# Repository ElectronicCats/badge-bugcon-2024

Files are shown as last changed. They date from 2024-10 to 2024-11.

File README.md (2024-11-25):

# Badge BugCON  2024

Badge Oficial BugCON 2024

## Getting started

1. Connect Badge via USB to your computer.
2. Open the serial port indicated for the badge on your computer through a program such as Arduino IDE, Putty or Screen at 115200 bauds.
3. The badge text should appear in the terminal.

## Tecnologia

### Community
- ESP32C6
- Baterias 2 x AA
- USB
- OLED 128×32 0.91 I2C SSD1306
- LEDS

### VIP
- ESP32C6
- Baterias 2 x AA
- USB
- GC9A01 Display TFT LCD Circular 1.28"
- LEDS

## How to build the firmware Community

Check the [Developer guide](./firmware/README.md) to learn how to build the firmware from scratch.

## How to build the firmware VIP

Check the [Developer guide CircuitPython](https://learn.adafruit.com/welcome-to-circuitpython/overview) to learn how to build the firmware from scratch.

Recommended development IDE [Thonny](https://thonny.org/)

## Gratitude
Do you want to say thank you? Tag these companies on social networks and show them your badge, thanks to them it is possible

- [BugCON Team](https://www.bugcon.org/)
- [ElectronicCats](https://electroniccats.com/)

## License

Electronic Cats invests time and resources providing this open source design, please support Electronic Cats and open-source hardware by purchasing products from Electronic Cats!

Designed by Electronic Cats.

Hardware released under an CERN Open Hardware Licence v1.2. See the LICENSE_HARDWARE file for more information.

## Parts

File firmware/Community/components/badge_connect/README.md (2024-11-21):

# Badge Connect library (Binary version)

This library is designed to provide a simple API in order to communicate electronic badges over a WiFi mesh network. It works using the [ESPNOW protocol](https://docs.espressif.com/projects/esp-idf/en/stable/esp32/api-reference/network/esp_now.html) developed by Espressif Systems.

## Features

- Send and receive messages between badges (messages can be of any data type)
- Set the badge's type (e.g. "BSides", "DragonJAR", "Ekoparty", and "BugCON")
- Get the badge's type

## Requirements

- At least two ESP32 development boards
- ESP-IDF installed in your computer
- `make` installed in your computer (optional)

## Installation

Add badge_connect_bin as a git submodule in your project.

```bash
git submodule add https://github.com/ElectronicCats/badge_connect_bin.git firmware/components/badge_connect
```

## Usage

1. Include the library in your source code.

```c
#include "badge_connect.h"
```

2. Initialize the library in your code.

```c
badge_connect_init();
```

3. Implement the callback function that will be called when a message is received.

```c
void receive_data_cb(badge_connect_recv_msg_t* msg) {
    // Do something with the received message
}
```

4. Register the callback function.

```c
badge_connect_register_recv_cb(receive_data_cb);
```

5. Set the badge's type, choose one of the following:

```c
badge_connect_set_bsides_badge();
badge_connect_set_dragonjar_badge();
badge_connect_set_ekoparty_badge();
badge_connect_set_bugcon_badge();
```

6. Send a message to another badge.

```c
char* data = "Hello, world!";
badge_connect_send(data, strlen(data));
```

7. Compile and flash!

## Examples

There is a folder called `examples` in this repository, you can use the `Makefile` in each example to compile and flash the firmware.

1. Get `idf.py` to your terminal session, if you followed the Espressif IDF installation guide, use `get_idf`.

```bash
get_idf
```

2. Go to the example folder you want to compile. For example, the `send_int` one.

```bash
cd examples/send_int
```

3. Set the board type you are using, skip if you are using an `ESP32`. For example, `ESP32-C6`.

```bash
idf.py set-target esp32c6
```

4. Set the serial port where the board is connected. For example, `/dev/ttyUSB0`.

```bash
export PORT=/dev/ttyUSB0
```

5. Compile, flash, and monitor the output.

```bash
make all
```

## License

Electronic Cats invests time and resources in providing this open-source design, please support Electronic Cats and open-source hardware by purchasing products from Electronic Cats!

Designed by Electronic Cats.

This library is released under a GNU AGPL v3.0 license. See the [LICENSE](LICENSE) file for more information.

Electronic Cats is a registered trademark, please do not use if you sell these PCBs.

June 2024

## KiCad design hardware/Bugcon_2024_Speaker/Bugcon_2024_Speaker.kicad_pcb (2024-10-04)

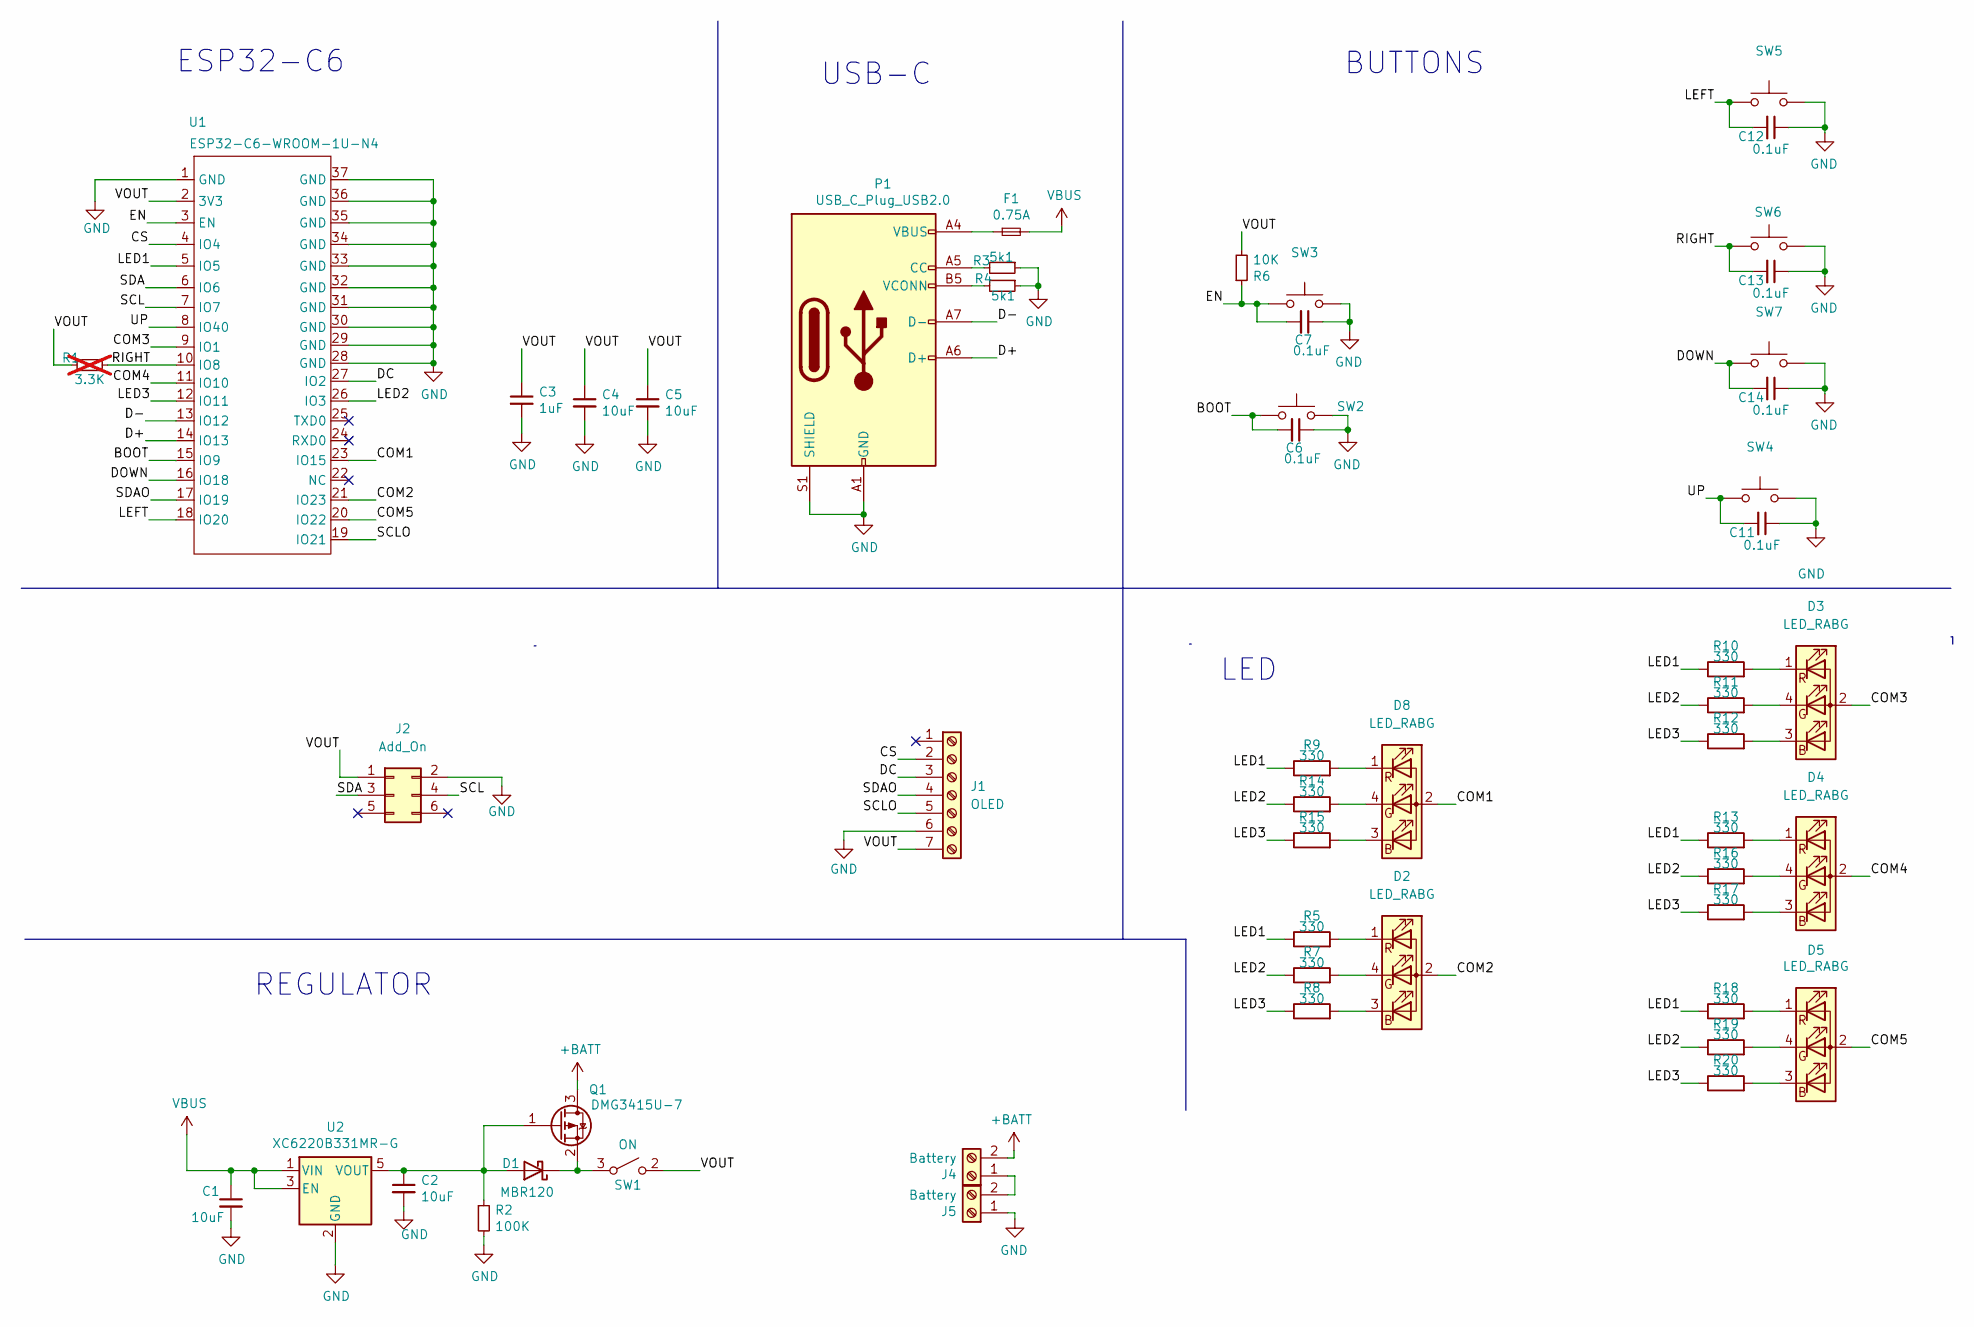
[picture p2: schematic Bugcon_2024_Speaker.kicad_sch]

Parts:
C1, C2, C4, C5: 10uF; C_0603_1608Metric; LCSC# C85713
C3: 1uF; C_0603_1608Metric; LCSC# C15849
C6, C7, C11, C12, C13, C14: 0.1uF; C_0603_1608Metric; LCSC# C478888
D1: MBR120; D_SOD-123F; LCSC# C130880
D2, D3, D4, D5, D8: LED_RABG; AAA3528SURKCGKC09
F1: 0.75A; Fuse_0805_2012Metric; LCSC# C1972808
J1: OLED; PinHeader_1x07_P2.54mm_Vertical
J2: Add_On; PinSocket_2x03_P2.54mm_Vertical; LCSC# C5116527
J4, J5: Battery; BATT_8BH-AA-A1AJ020_MYG; LCSC# C5290181
P1: USB_C_Plug_USB2.0; C393939; LCSC# C393939
Q1: DMG3415U-7; SOT-23; LCSC# C96616
R1: 3.3K; R_0603_1608Metric; LCSC# C403480; not fitted
R2: 100K; R_0603_1608Metric; LCSC# C25803
R3, R4: 5k1; R_0603_1608Metric; LCSC# C113390
R5, R7, R8, R9, R10, R11, R12, R13, R14, R15, R16, R17, R18, R19, R20: 330; R_0603_1608Metric; LCSC# C25231
R6: 10K; R_0603_1608Metric; LCSC# C217281
SW1: ON; MSK12C02; LCSC# C431540
SW2, SW3, SW4, SW5, SW6, SW7: SW_SPST_TL3342; LCSC# C318889
U1: ESP32-C6-WROOM-1U-N4; XCVR_ESP32-C6-WROOM-1-N8
U2: XC6220B331MR-G; SOT-23-5; LCSC# C86534

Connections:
+BATT: J4.2, Q1.3 (D)
/BOOT: C6.2, SW2.2, U1.15 (IO9)
/COM1: D8.2 (A), U1.23 (IO15)
/COM2: D2.2 (A), U1.21 (IO23)
/COM3: D3.2 (A), U1.9 (IO1)
/COM4: D4.2 (A), U1.11 (IO10)
/COM5: D5.2 (A), U1.20 (IO22)
/CS: J1.2, U1.4 (IO4)
/D+: P1.A6 (D+), U1.14 (IO13)
/D-: P1.A7 (D-), U1.13 (IO12)
/DC: J1.3, U1.27 (IO2)
/DOWN: C14.2, SW7.2, U1.16 (IO18)
/EN: C7.2, R6.1, SW3.2, U1.3 (EN)
/LED1: R5.1, R9.1, R10.1, R13.1, R18.1, U1.5 (IO5)
/LED2: R7.1, R11.1, R14.1, R16.1, R19.1, U1.26 (IO3)
/LED3: R8.1, R12.1, R15.1, R17.1, R20.1, U1.12 (IO11)
/LEFT: C12.2, SW5.2, U1.18 (IO20)
/RIGHT: C13.2, R1.1, SW6.2, U1.10 (IO8)
/SCL: J2.4, U1.7 (IO7)
/SCLO: J1.5, U1.19 (IO21)
/SDA: J2.3, U1.6 (IO6)
/SDAO: J1.4, U1.17 (IO19)
/UP: C11.2, SW4.2, U1.8 (IO40)
/VOUT: C3.1, C4.1, C5.1, J1.7, J2.1, R1.2, R6.2, SW1.2 (B), U1.2 (3V3)
GND: C1.2, C2.2, C3.2, C4.2, C5.2, C6.1, C7.1, C11.1, C12.1, C13.1, C14.1, J1.6, J2.2, J5.1, P1.A1 (GND), P1.A12 (GND), P1.B1 (GND), P1.B12 (GND), P1.S1 (SHIELD), R2.2, R3.1, R4.1, SW2.1, SW3.1, SW4.1, SW5.1, SW6.1, SW7.1, U1.1 (GND), U1.28 (GND), U1.29 (GND), U1.30 (GND), U1.31 (GND), U1.32 (GND), U1.33 (GND), U1.34 (GND), U1.35 (GND), U1.36 (GND), U1.37 (GND), U2.2 (GND)
unnamed: C2.1, D1.2 (A), Q1.1 (G), R2.1, U2.5 (VOUT)
unnamed: D1.1 (K), Q1.2 (S), SW1.3 (A)
unnamed: D2.3 (BK), R8.2
unnamed: D2.4 (GK), R7.2
unnamed: D2.1 (RK), R5.2
unnamed: D3.3 (BK), R12.2
unnamed: D3.4 (GK), R11.2
unnamed: D3.1 (RK), R10.2
unnamed: D4.3 (BK), R17.2
unnamed: D4.4 (GK), R16.2
unnamed: D4.1 (RK), R13.2
unnamed: D5.3 (BK), R20.2
unnamed: D5.4 (GK), R19.2
unnamed: D5.1 (RK), R18.2
unnamed: D8.3 (BK), R15.2
unnamed: D8.4 (GK), R14.2
unnamed: D8.1 (RK), R9.2
unnamed: F1.1, P1.A4 (VBUS), P1.A9 (VBUS), P1.B4 (VBUS), P1.B9 (VBUS)
unnamed: J4.1, J5.2
unnamed: P1.A5 (CC), R3.2
unnamed: P1.B5 (VCONN), R4.2
VBUS: C1.1, F1.2, U2.1 (VIN), U2.3 (EN)

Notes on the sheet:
BUTTONS
LED
ESP32-C6
REGULATOR
USB-C

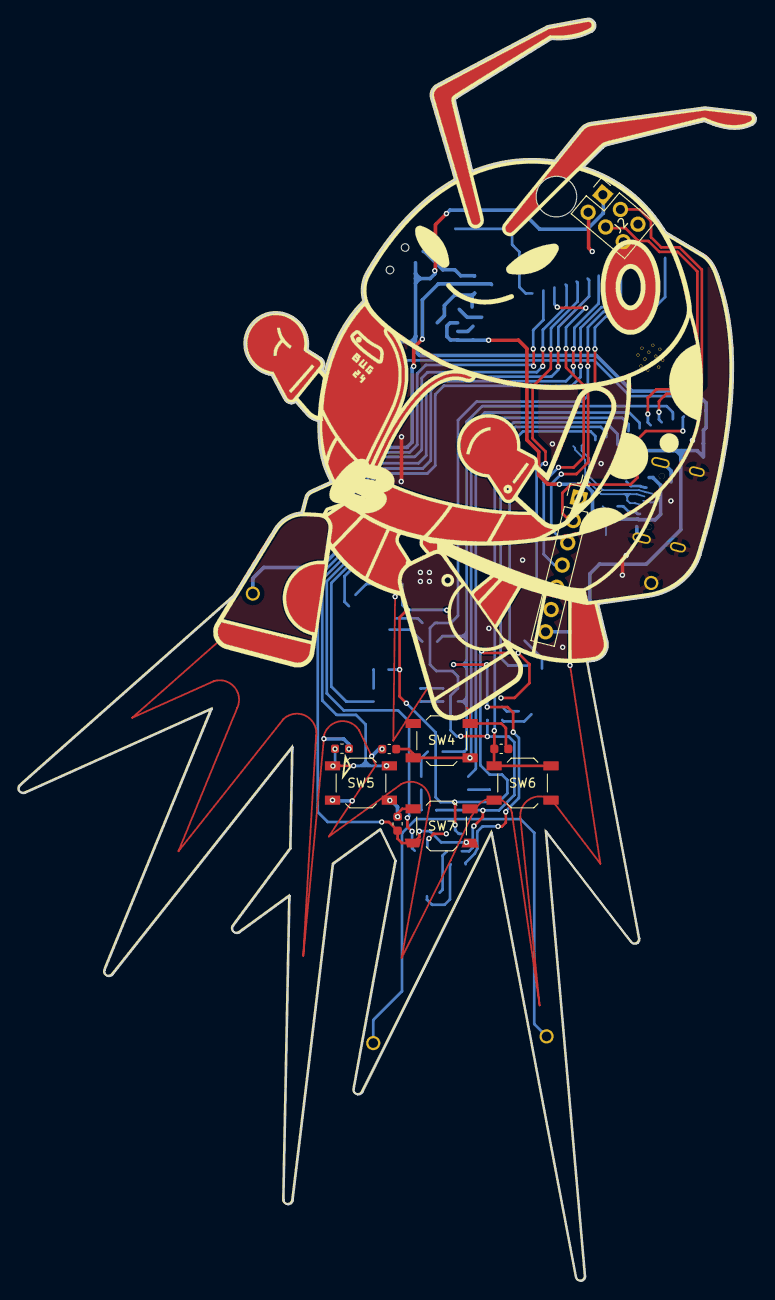
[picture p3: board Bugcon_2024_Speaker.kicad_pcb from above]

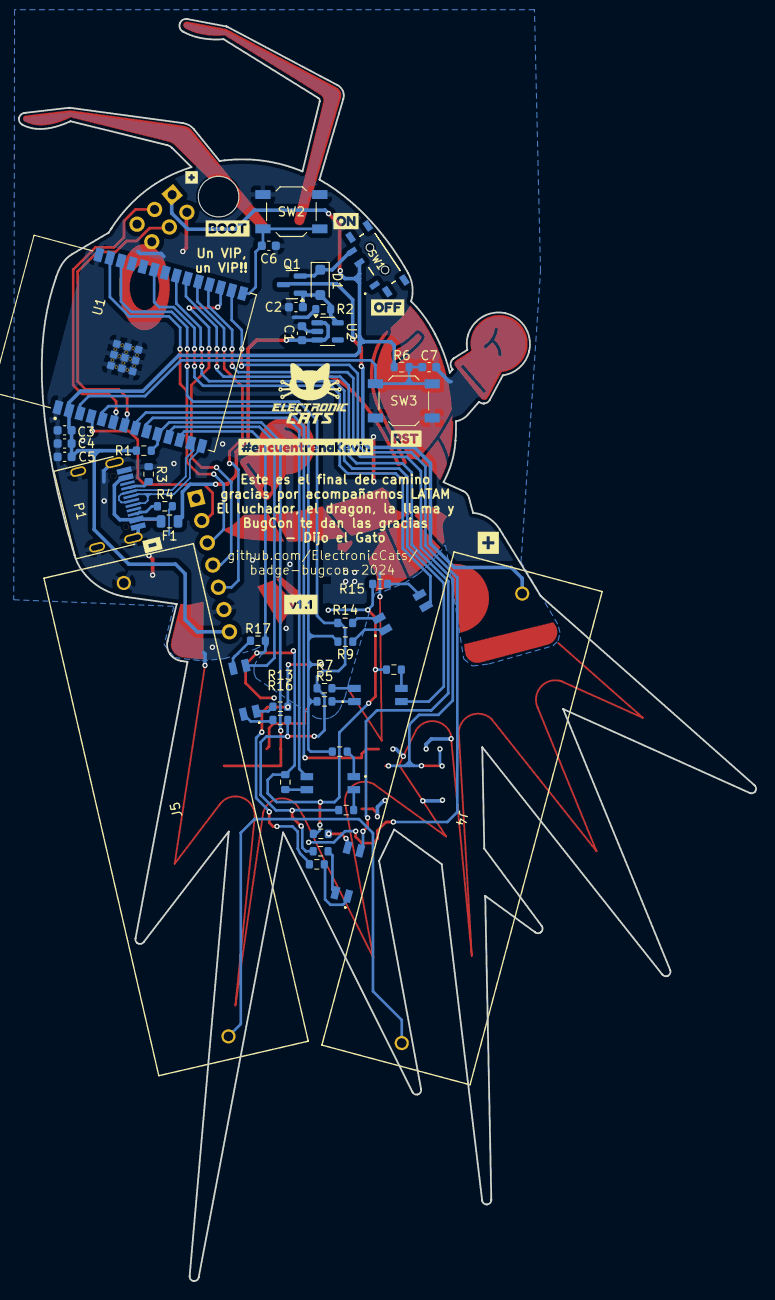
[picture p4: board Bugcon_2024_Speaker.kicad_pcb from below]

Board: 2 copper layers, 81.7 x 139.8 mm, 63 parts (52 on the bottom side), 47 nets.

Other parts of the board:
Ref**: Val**; 01.BugCON Personajes-
kibuzzard-66F1E44B: G***; kibuzzard-66F1E44B
kibuzzard-66F1E442: G***; kibuzzard-66F1E442
kibuzzard-66F1E456: G***; kibuzzard-66F1E456
kibuzzard-66F1E462: G***; kibuzzard-66F1E462
kibuzzard-66FD9EC0: G***; kibuzzard-66FD9EC0
kibuzzard-66FD9F77: G***; kibuzzard-66FD9F77
kibuzzard-666C8A00: G***; kibuzzard-666C8A00
kibuzzard-666C89F7: G***; kibuzzard-666C89F7
kibuzzard-670026B6: G***; kibuzzard-670026B6

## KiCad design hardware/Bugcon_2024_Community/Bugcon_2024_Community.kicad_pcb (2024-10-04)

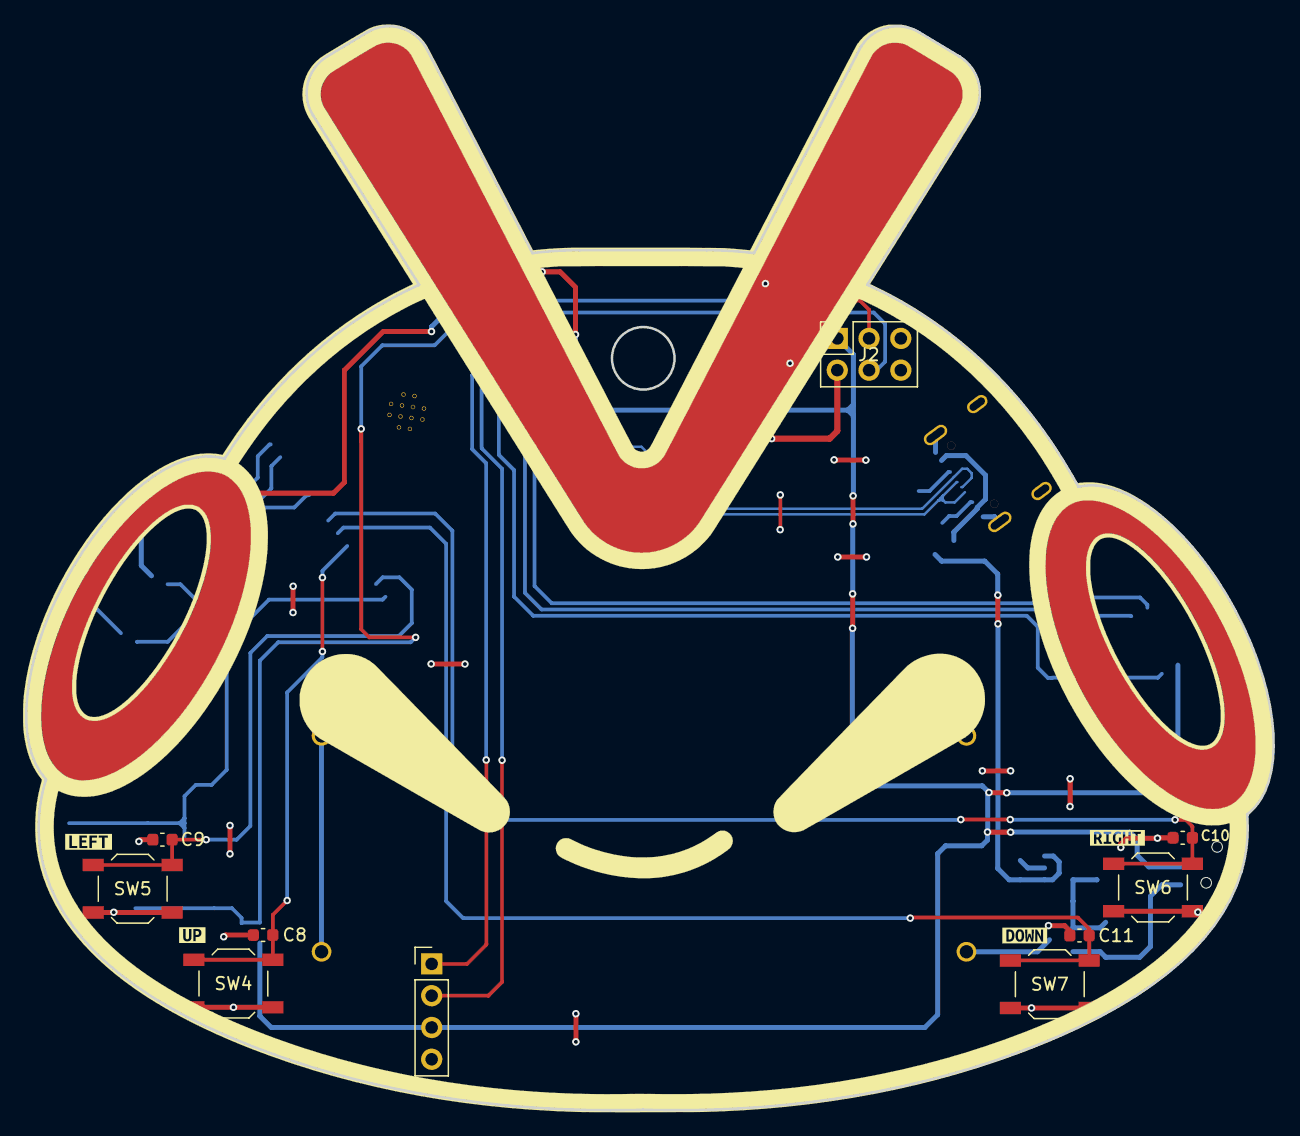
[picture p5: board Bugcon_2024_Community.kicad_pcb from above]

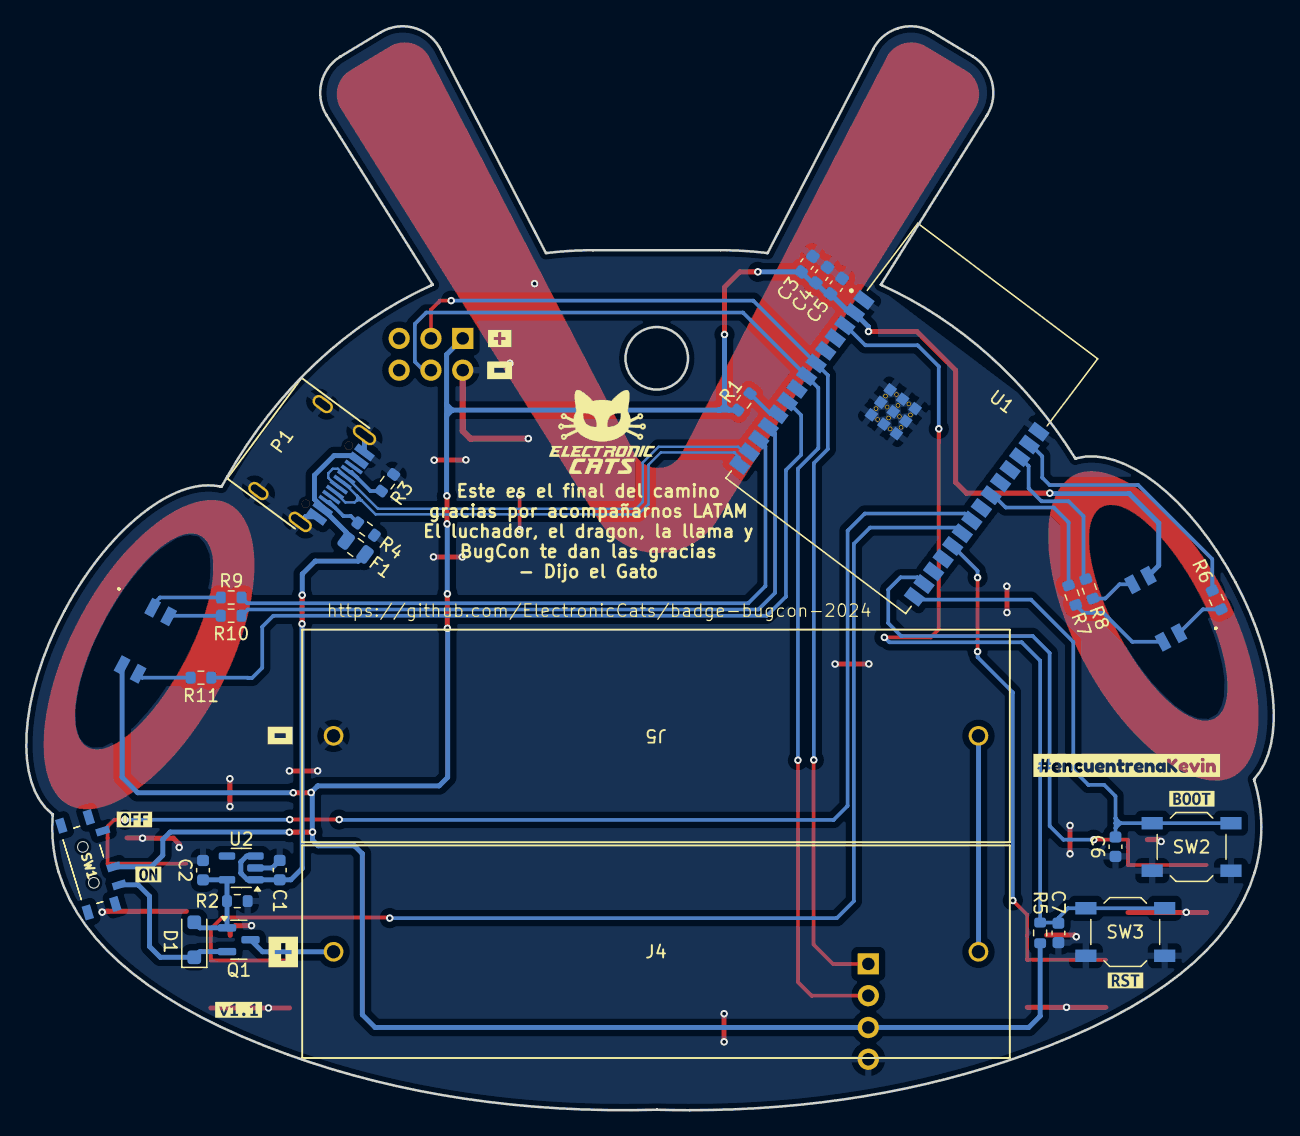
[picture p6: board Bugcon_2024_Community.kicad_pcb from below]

Board: 2 copper layers, 99.7 x 86.6 mm, 56 parts (41 on the bottom side), 33 nets.

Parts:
C1, C2, C4, C5: 10uF; C_0603_1608Metric
C3: 1uF; C_0603_1608Metric
C6, C7, C8, C9, C10, C11: 0.1uF; C_0603_1608Metric
D1: MBR120; D_SOD-123F
D2, D3: LED_RABG; AAA3528SURKCGKC09
F1: 0.75A; Fuse_0805_2012Metric
J2: Add_On; PinSocket_2x03_P2.54mm_Vertical
J3: OLED; Display OLED 128 x32
J4, J5: Battery; BATT_8BH-AA-A1AJ020_MYG
P1: USB_C_Plug_USB2.0; C393939
Q1: DMG3415U-7; SOT-23
R1: 3.3K; R_0603_1608Metric
R2: 100K; R_0603_1608Metric
R3, R4: 5k1; R_0603_1608Metric
R5: 10K; R_0603_1608Metric
R6, R7, R8, R9, R10, R11: 330; R_0603_1608Metric
Ref**: Val**; 02.BugCON Personajes
SW1: ON; MSK12C02
SW2, SW3, SW4, SW5, SW6, SW7: SW_SPST_TL3342
U1: ESP32-C6-WROOM-1U-N4; XCVR_ESP32-C6-WROOM-1-N8
U2: XC6220B331MR-G; SOT-23-5
kibuzzard-66F475F7: G***; kibuzzard-66F475F7
kibuzzard-66F4760F: G***; kibuzzard-66F4760F
kibuzzard-66F4761D: G***; kibuzzard-66F4761D
kibuzzard-66F4762A: G***; kibuzzard-66F4762A
kibuzzard-66F47603: G***; kibuzzard-66F47603
kibuzzard-66F47638: G***; kibuzzard-66F47638
kibuzzard-66F47642: G***; kibuzzard-66F47642
kibuzzard-66F47655: G***; kibuzzard-66F47655
kibuzzard-66F47715: G***; kibuzzard-66F47715
kibuzzard-66FD9F77: G***; kibuzzard-66FD9F77
kibuzzard-666C8A00: G***; kibuzzard-666C8A00
kibuzzard-666C89F7, kibuzzard-666C89F7#2: G***; kibuzzard-666C89F7
kibuzzard-6700283A: G***; kibuzzard-6700283A

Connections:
+BATT: J4.2, Q1.3 (D)
/BOOT: C6.2, SW2.2, U1.15 (IO9)
/D+: P1.A6 (D+), U1.14 (IO13)
/D-: P1.A7 (D-), U1.13 (IO12)
/DOWN: C11.2, SW7.2, U1.20 (IO22)
/EN: C7.2, R5.1, SW3.2, U1.3 (EN)
/LED1: R6.1, U1.27 (IO2)
/LED2: R7.1, U1.23 (IO15)
/LED3: R8.1, U1.26 (IO3)
/LED4: R9.1, U1.12 (IO11)
/LED5: R10.1, U1.11 (IO10)
/LED6: R11.1, U1.9 (IO1)
/LEFT: C9.2, SW5.2, U1.16 (IO18)
/RIGHT: C10.2, SW6.2, U1.21 (IO23)
/SCL: J2.4, J3.2, U1.7 (IO7)
/SDA: J2.3, J3.1, U1.6 (IO6)
/UP: C8.2, SW4.2, U1.19 (IO21)
/VOUT: C3.1, C4.1, C5.1, D2.2 (A), D3.2 (A), J2.1, J3.3, R1.2, R5.2, SW1.2 (B), U1.2 (3V3)
GND: C1.2, C2.2, C3.2, C4.2, C5.2, C6.1, C7.1, C8.1, C9.1, C10.1, C11.1, J2.2, J3.4, J5.1, P1.A1 (GND), P1.S1 (SHIELD), R2.2, R3.1, R4.1, SW2.1, SW3.1, SW4.1, SW5.1, SW6.1, SW7.1, U1.1 (GND), U1.28 (GND), U1.29 (GND), U1.30 (GND), U1.31 (GND), U1.32 (GND), U1.33 (GND), U1.34 (GND), U1.35 (GND), U1.36 (GND), U1.37 (GND), U2.2 (GND)
unnamed: C2.1, D1.2 (A), Q1.1 (G), R2.1, U2.5 (VOUT)
unnamed: D1.1 (K), Q1.2 (S), SW1.3 (A)
unnamed: D2.3 (BK), R8.2
unnamed: D2.4 (GK), R7.2
unnamed: D2.1 (RK), R6.2
unnamed: D3.3 (BK), R11.2
unnamed: D3.4 (GK), R10.2
unnamed: D3.1 (RK), R9.2
unnamed: F1.1, P1.A4 (VBUS)
unnamed: J4.1, J5.2
unnamed: P1.A5 (CC), R3.2
unnamed: P1.B5 (VCONN), R4.2
unnamed: R1.1, U1.10 (IO8)
VBUS: C1.1, F1.2, U2.1 (VIN), U2.3 (EN)

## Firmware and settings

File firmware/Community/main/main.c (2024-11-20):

#include <stdio.h>

#include "adv_scan_module.h"
#include "badge_connect.h"
#include "badge_link_module.h"
#include "buzzer.h"
#include "cat_console.h"
#include "esp_log.h"
#include "esp_random.h"
#include "esp_timer.h"
#include "flash_fs.h"
#include "flash_fs_screens.h"
#include "keyboard_module.h"
#include "menus_module.h"
#include "oled_screen.h"
#include "open_thread.h"
#include "preferences.h"
#include "rgb_ledc_controller.h"
#include "screen_saver.h"
#include "sd_card.h"
#include "web_file_browser.h"
#include "wifi_app.h"

// Define the GPIO pins for the Red, Green, and Blue LEDs
#define GPIO_LED_RED_1   2
#define GPIO_LED_GREEN_1 15
#define GPIO_LED_BLUE_1  3
#define GPIO_LED_RED_2   11
#define GPIO_LED_GREEN_2 10
#define GPIO_LED_BLUE_2  1

// Define colors as RGB values in hexadecimal
#define RED      0x00FFFF  // Red color for common anode (invert the bits)
#define GREEN    0xFF00FF  // Green color for common anode (invert the bits)
#define BLUE     0xFFFF00  // Blue color for common anode (invert the bits)
#define YELLOW   0x0000FF  // Yellow color for common anode (invert the bits)
#define VIOLET   0x11DD11  // Violet color for common anode (invert the bits)
#define NO_COLOR 0xFFFFFF  // No color (all LEDs off)

static const char* TAG = "main";

/**
 * @brief Task that generates random colors and sets them to the RGB LEDs
 */
void random_colors_task() {
  // Create an instance of the RGB LED structure and initialize it with the
  // defined GPIO pins and LEDC channels
  rgb_led_t led1 =
      rgb_led_new(GPIO_LED_RED_1, GPIO_LED_GREEN_1, GPIO_LED_BLUE_1,
                  LEDC_CHANNEL_0, LEDC_CHANNEL_1, LEDC_CHANNEL_2);
  rgb_led_t led2 =
      rgb_led_new(GPIO_LED_RED_2, GPIO_LED_GREEN_2, GPIO_LED_BLUE_2,
                  LEDC_CHANNEL_3, LEDC_CHANNEL_4, LEDC_CHANNEL_5);
  //...you can add one more eg: led2.It is limited to 2 leds due to the LEDC
  // module having only 8 channels available.

  // Initialize the RGB LED, check for any errors during the process
  ESP_ERROR_CHECK(rgb_led_init(&led1));
  ESP_ERROR_CHECK(rgb_led_init(&led2));

  for (uint8_t i = 0; i < 3; i++) {
    rgb_led_set_color(&led1, RED);
    rgb_led_set_color(&led2, NO_COLOR);
    vTaskDelay(pdMS_TO_TICKS(200));
    rgb_led_set_color(&led1, NO_COLOR);
    rgb_led_set_color(&led2, BLUE);
    vTaskDelay(pdMS_TO_TICKS(200));
  }
  rgb_led_set_color(&led2, NO_COLOR);

  while (1) {
    vTaskDelay(pdMS_TO_TICKS(1000 * 60 * 5));  // 5 minutes
    for (uint8_t i = 0; i < 20; i++) {
      // Color must be in format 0xRRGGBB
      uint8_t color1 = esp_random();
      uint8_t color2 = esp_random();
      uint8_t color3 = esp_random();
      uint32_t color_led1 = (color1 << 16) | (color2 << 8) | color3;
      uint32_t color_led2 = (color3 << 16) | (color2 << 8) | color1;

      rgb_led_set_color(&led1, color_led1);
      rgb_led_set_color(&led2, color_led1);
      vTaskDelay(pdMS_TO_TICKS(500));
    }
    rgb_led_set_color(&led1, NO_COLOR);
    rgb_led_set_color(&led2, NO_COLOR);
  }
}

void app_main() {
#if !defined(CONFIG_MAIN_DEBUG)
  esp_log_level_set(TAG, ESP_LOG_NONE);
#endif
  preferences_begin();
  // preferences_clear();
  if (preferences_get_int("dp_select", 0) == 0) {
    preferences_put_int("dp_select", 9);
  }

  // flash_fs_begin(flash_fs_screens_handler);
  // sd_card_begin();
  keyboard_module_begin();
  menus_module_begin();
  if (!preferences_get_int("flogin", 0)) {
    screen_saver_stop();
  }

  xTaskCreate(random_colors_task, "random_colors_task", 2048, NULL, 1, NULL);

  // adv_scanner_module_begin();
  // Always start the console at the end
  // cat_console_begin();
  // play_artu();
}

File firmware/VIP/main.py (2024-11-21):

import asyncio
import gc
from kb_module import kb_module_init
from screen import screen_init, get_screen
from screen_saver import screen_saver_init
import displayio
from leds import leds_init

from eye import eye_init, eye_deinit
    
async def _sleeper():
    while True:
        await asyncio.sleep_ms(5000)
        gc.collect()

async def main():
    displayio.release_displays()
    kb_module_init()
    screen_init()
    leds_init()
    screen_saver_init()
    await _sleeper()

def main_run():
    asyncio.run(main())

if __name__ == "__main__":
    asyncio.run(main())

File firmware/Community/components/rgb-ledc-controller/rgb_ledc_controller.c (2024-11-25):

/**
 * @file rgb_ledc_controller.c
 * @author Massimo Dalla Bona
 * @date 04.07.2023
 *  @version 1.0
 * @brief File containing the implementation of the RGB LED control library.
 *
 * This library provides an interface to control multiple RGB LEDs independently
 * on an ESP32 microcontroller. It utilizes the microcontroller's GPIO and LEDC
 * functionalities to provide precise control over the color and brightness of
 * each LED. The library supports the configuration of each LED's color, as well
 * as enabling various lighting effects including blinking, transition, and
 * breathing effects, with customizable timing parameters. Each RGB LED can be
 * individually controlled, allowing for complex light effects across multiple
 * LEDs.
 *
 * @note This implementation is compatible with the ESP-IDF development
 * framework, version 5.0.2.
 *
 * @note This software is licensed under the Creative Commons
 * Attribution-NonCommercial-NoDerivatives 4.0 International License. To view a
 * copy of this license, visit
 * http://creativecommons.org/licenses/by-nc-nd/4.0/. You may not use,
 * distribute, modify, or sell this software without the express permission of
 * the author. For more information, please contact the author at
 * massimodallabona@gmail.com.
 */

#include "rgb_ledc_controller.h"
#include "driver/gpio.h"
#include "driver/ledc.h"
#include "esp_check.h"
#include "esp_err.h"
#include "esp_log.h"
#include "esp_timer.h"
#include "freertos/FreeRTOS.h"
#include "freertos/semphr.h"
#include "freertos/task.h"
#include "string.h"

#define MIN(a, b) \
  (((a) < (b))    \
       ? (a)      \
       : (b))  // Macro function to get the minimum value between two numbers.

static const char* TAG = "LED_RGB";

// RGB LED Effect State Enum
// This enum represents the different states of the RGB LED effects.
typedef enum {
  RGB_LED_EFFECT_NONE,        // No effect active
  RGB_LED_EFFECT_TRANSITION,  // Transition effect active
  RGB_LED_EFFECT_BREATH,      // Breath effect active
  RGB_LED_EFFECT_BLINK        // Blink effect active
} rgb_led_effect_state_t;

// RGB LED Transition Structure
// This structure represents the transition effect data for an RGB LED.
typedef struct {
  rgb_led_t* led;                // Pointer to the RGB LED
  esp_timer_handle_t timer;      // Timer handle for the transition effect
  uint32_t color;                // Color of the transition effect
  void (*callback)(rgb_led_t*);  // Callback function
} rgb_led_transition_t;

// RGB LED Breath Structure
// This structure represents the breath effect data for an RGB LED.
typedef struct {
  rgb_led_t* led;            // Pointer to the RGB LED
  esp_timer_handle_t timer;  // Timer handle for the breath effect
  uint32_t color;            // Color of the breath effect
  float brightness;          // Current brightness of the LED
  float step;                // Step size for increasing/decreasing brightness
} rgb_led_breath_t;

// RGB LED Blink Structure
// This structure represents the blink effect data for an RGB LED.
typedef struct {
  rgb_led_t* led;            // Pointer to the RGB LED
  esp_timer_handle_t timer;  // Timer handle for the blink effect
  uint32_t color;            // Color of the blink effect
  uint32_t time_on;          // Duration of the LED ON state during each pulse
  uint32_t time_off;         // Duration of the LED OFF state during each pulse
  uint32_t time_out;         // Timeout duration for the blink effect
  uint8_t pulse_count;       // Number of pulses for the blink effect
} rgb_led_blink_t;

// RGB LED Effects Structure
// This structure represents the effects data for an RGB LED.
typedef struct {
  rgb_led_t* led;                          // Pointer to the RGB LED
  rgb_led_effect_state_t effect_state;     // Current effect state
  rgb_led_transition_t transition_effect;  // Transition effect data
  rgb_led_breath_t breath_effect;          // Breath effect data
  rgb_led_blink_t blink_effect;            // Blink effect data
  // Add any additional fields you need for other effects
} rgb_led_effects_t;

#define COLOR_BLACK 0x000000

// Maximum number of LEDs for breath effect
#define MAX_RGB_LEDS 2  // max 8 ledc_channels -> 3 x 2 = 6pin

// Array to hold the breath and blink effect data for multiple LEDs
static rgb_led_effects_t led_effects[MAX_RGB_LEDS];

// Number of breath and blink effect LEDs currently active
static int num_led_effects = 0;

static int get_led_index(rgb_led_t* led) {
  // Check if the blink effect is already active for the specified LED
  for (int i = 0; i < num_led_effects; i++) {
    if (led_effects[i].led == led) {
      return i;
    }
  }
  return -1;
}

/**
 * @brief Sets up a LEDC channel to control a specific LED.
 *
 * @description This function sets up one of the ESP32's LEDC (LED Controller)
 * channels to control a specific LED. It first sets up a LEDC timer with a
 * predefined configuration (8-bit duty resolution, 5000 Hz frequency,
 * high-speed mode, timer number 0). It then configures the LEDC channel to use
 * the provided GPIO and the LEDC timer. The LED is initially off (duty = 0).
 * The function returns ESP_OK if the setup was successful. If there was an
 * error, it returns an appropriate ESP_ERR code.
 *
 * @param led_gpio The GPIO number of the LED to control.
 * @param led_channel The LEDC channel to use for the LED.
 * @return esp_err_t ESP_OK if successful, or an error code if not.
 */
static esp_err_t setup_ledc(int led_gpio, ledc_channel_t led_channel) {
  // Set LEDC timer configuration
  ledc_timer_config_t ledc_timer = {
      .duty_resolution = LEDC_TIMER_8_BIT,  // Resolution of PWM duty
      .freq_hz = 5000,                      // Frequency of PWM signal
      .speed_mode = LEDC_LOW_SPEED_MODE,    // Timer mode
      .timer_num = LEDC_TIMER_0             // Timer index
  };

  // Set the configuration
  esp_err_t err = ledc_timer_config(&ledc_timer);
  if (err != ESP_OK)
    return err;

  // Prepare individual configuration for each LED
  ledc_channel_config_t ledc_channel_cfg = {
      .channel = led_channel,
      .duty = 0,  // Initial duty value (LED is off)
      .gpio_num = led_gpio,
      .speed_mode = LEDC_LOW_SPEED_MODE,
      .hpoint = 0,
      .timer_sel = LEDC_TIMER_0};

  ledc_fade_func_install(NULL);

  // Set the configuration
  return ledc_channel_config(&ledc_channel_cfg);
}
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

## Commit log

2024-08-14 feat(Hw): Add community and speaker boards
    [Bugcon_2024_Community.kicad_pcb, Bugcon_2024_Community.kicad_sch, Bugcon_2024_Speaker.kicad_pcb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]
2024-08-22 feat(Hw): Update community PCB
    [Bugcon_2024_Community.kicad_pcb, Bugcon_2024_Community.kicad_sch]
2024-08-22 feat(Hw): Update community route
    [Bugcon_2024_Community.kicad_pcb]
2024-09-03 feat(Hw): Update route
    [Bugcon_2024_Speaker.kicad_pcb, Bugcon_2024_Speaker.kicad_sch]
2024-09-05 feat(Hw): Update ground areas
    [Bugcon_2024_Community.kicad_pcb, Bugcon_2024_Community.kicad_sch, Bugcon_2024_Speaker.kicad_pcb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]
2024-09-06 feat(Hw): Change LEDs
    [Bugcon_2024_Community.kicad_pcb, Bugcon_2024_Community.kicad_sch, Bugcon_2024_Speaker.kicad_pcb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]
2024-09-23 fix(hw): fix pins for OLED
    [Bugcon_2024_Speaker.kicad_sch]
2024-09-23 feat: add labels and logos
    [Bugcon_2024_Speaker.kicad_pcb]
2024-10-02 feat: add more labels
    [Bugcon_2024_Community.kicad_pcb, Bugcon_2024_Speaker.kicad_pcb]
2024-11-17 feat: add eko party firmware
    [partitions.csv, partitions_no_ota.csv]
2024-11-19 feat: add leds animation at startup
2024-11-19 fix: old keyboard cb params
    [lobby_manager.c, speed_bag_game.h]
2024-11-19 feat: recrease rssi filter for games
2024-11-19 feat: add leds animation every 5 minutes
2024-11-19 feat: add bugcon logo
    [main.c]
2024-11-21 feat: add paths firmware
    [partitions.csv, partitions_no_ota.csv]
